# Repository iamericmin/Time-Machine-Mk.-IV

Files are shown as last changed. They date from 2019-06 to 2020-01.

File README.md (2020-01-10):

# Time Machine Mk. IV
# [Full write-up is on my website!](https://iamericmin.github.io/tm4.html)
Peekaboo!
## Homebrew cyberpunk Cortex M4 "smart"watch with BLE radio

Project status: all bugs not fixed before January 1st 2020 are now officially features

# Hi!
I am Eric Min and I'm a 18 year old teenager from Seoul, South Korea. This is my first major project in circuit design and firmware development. It is a cyberpunk inspired wristwatch leveraging the low-power and Bluetooth Low Energy features of Nordic's nRF52832. I think it looks pretty dope! :)

# THE JUICY STUFF:
-   PROCESSOR: nRF52832 Soc. 64MHz ARM cortex M4 with 64k RAM and 512k flash.
-   FIRMWARE: Espruino JS interpreter + JS code layer
-   POWER: 12mm CR1225 coin cell battery. About two weeks of battery life.
-   DISPLAY: If you can call it a display. Dual 7-segment LEDs with five auxiliary LEDs.
-   INPUT: Triple momentary tactile switches.
-   SOUND: Mini piezo speaker.
-   DIMENSIONS: 43.18mm width and length, 10.2mm thickness.
-   STRAP: 22mm NATO strap.

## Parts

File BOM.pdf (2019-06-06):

Description | Quantity Unit Price Extended Price
SWITCH TACTILE SPST-NO 0.05A 32V | 3 | 0.52 $0.52
AUDIO MAGNETIC XDCR 2-4V SMD | 1 | 3.03 $6.06
7-SEG. DISPLAY THROUGH HOLE | 2 | 1.59 $4.77
BATTERY RETAINER COIN 12MM SMD | 1 | 0.91 $3.64
RES SMD 330 OHM 0.5% 1/10W 0805 | 12 | 0.11 $0.55
MDBT42Q NRF52832 BASED BLE MODUL | 1 | 10.1 $60.60
LED BLUE CLEAR 1206 SMD | 5 | 0.39 $2.73

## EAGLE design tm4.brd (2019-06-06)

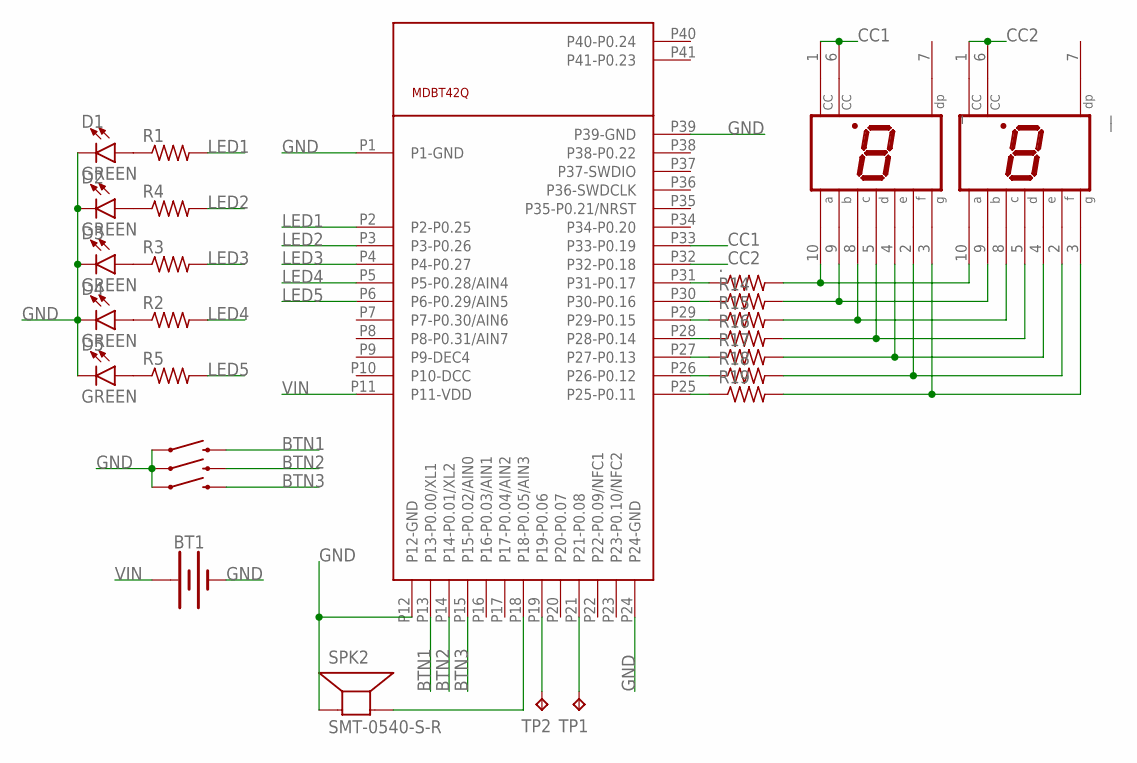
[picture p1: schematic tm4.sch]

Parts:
.: R-US_M0805; M0805
BT1: BATTERY-12MM_SMD; BATTCON_12MM
D1, D2, D3, D4, D5: GREEN; LED-1206
R1, R2, R3, R4, R5, R14, R15, R16, R17, R18, R19: R-US_M0805; M0805
SPK2: SMT-0540-S-R
TP1, TP2: TPTP19R; TP19R
U$1: MDBT42Q; MDBT40
_: HD-A103; HDSP-A
__: HD-A103; HDSP-A
____: MOMENTARY-SWITCH-SPST-SMD-6.2MM-TALL; TACTILE_SWITCH_SMD_6.2MM_TALL
_____: MOMENTARY-SWITCH-SPST-SMD-6.2MM-TALL; TACTILE_SWITCH_SMD_6.2MM_TALL
______: MOMENTARY-SWITCH-SPST-SMD-6.2MM-TALL; TACTILE_SWITCH_SMD_6.2MM_TALL

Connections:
A: ..2, _.10 (A), __.10 (A)
B: R14.2, _.9 (B), __.9 (B)
BTN1: U$1.P13 (P13-P0.00/XL1), ____.B2 (2)
BTN2: U$1.P14 (P14-P0.01/XL2), _____.B2 (2)
BTN3: U$1.P15 (P15-P0.02/AIN0), ______.B2 (2)
C: R15.2, _.8 (C), __.8 (C)
CC1: U$1.P33 (P33-P0.19), _.1 (CC), _.6 (CC)
CC2: U$1.P32 (P32-P0.18), __.1 (CC), __.6 (CC)
D: R16.2, _.5 (D), __.5 (D)
E: R17.2, _.4 (E), __.4 (E)
F: R18.2, _.2 (F), __.2 (F)
G: R19.2, _.3 (G), __.3 (G)
GND: BT1.GND (-), D1.C, D2.C, D3.C, D4.C, D5.C, SPK2.- (+), U$1.P1 (P1-GND), U$1.P12 (P12-GND), U$1.P24 (P24-GND), U$1.P39 (P39-GND), ____.A2 (1), _____.A2 (1), ______.A2 (1)
LED1: R1.2, U$1.P2 (P2-P0.25)
LED2: R4.2, U$1.P3 (P3-P0.26)
LED3: R3.2, U$1.P4 (P4-P0.27)
LED4: R2.2, U$1.P5 (P5-P0.28/AIN4)
LED5: R5.2, U$1.P6 (P6-P0.29/AIN5)
unnamed: ..1, U$1.P31 (P31-P0.17)
unnamed: R14.1, U$1.P30 (P30-P0.16)
unnamed: R15.1, U$1.P29 (P29-P0.15)
unnamed: D1.A, R1.1
unnamed: D2.A, R4.1
unnamed: D3.A, R3.1
unnamed: D4.A, R2.1
unnamed: R16.1, U$1.P28 (P28-P0.14)
unnamed: R17.1, U$1.P27 (P27-P0.13)
unnamed: R18.1, U$1.P26 (P26-P0.12)
unnamed: R19.1, U$1.P25 (P25-P0.11)
unnamed: SPK2.+ (-), U$1.P18 (P18-P0.05/AIN3)
unnamed: D5.A, R5.1
unnamed: TP1.TP, U$1.P21 (P21-P0.08)
unnamed: TP2.TP, U$1.P19 (P19-P0.06)
VIN: BT1.PWR@1 (+), U$1.P11 (P11-VDD)

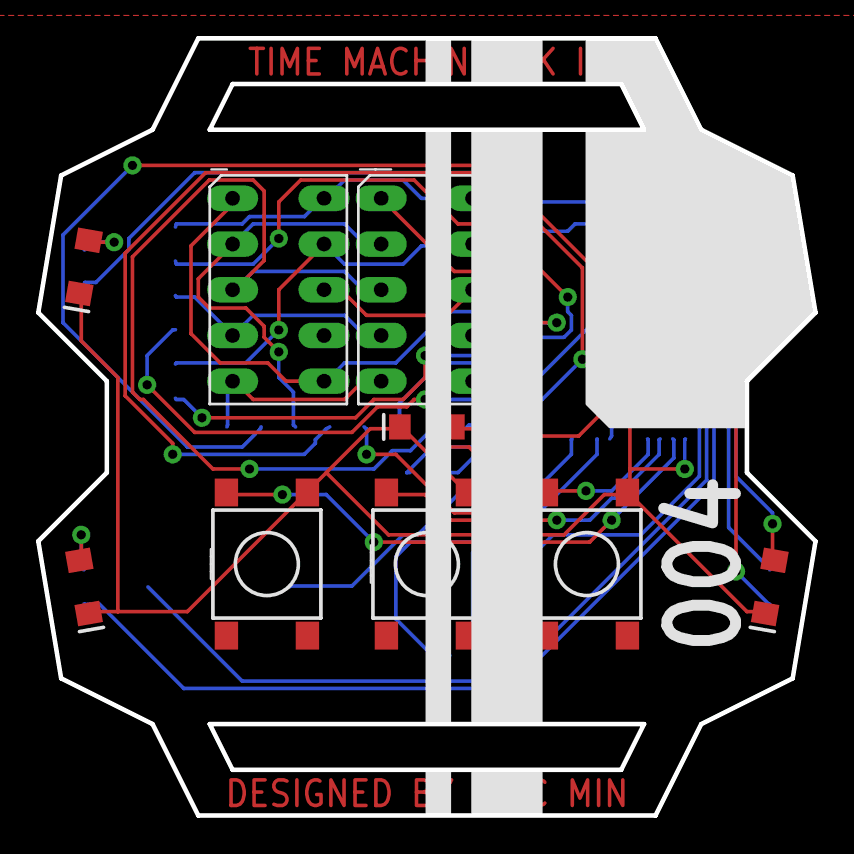
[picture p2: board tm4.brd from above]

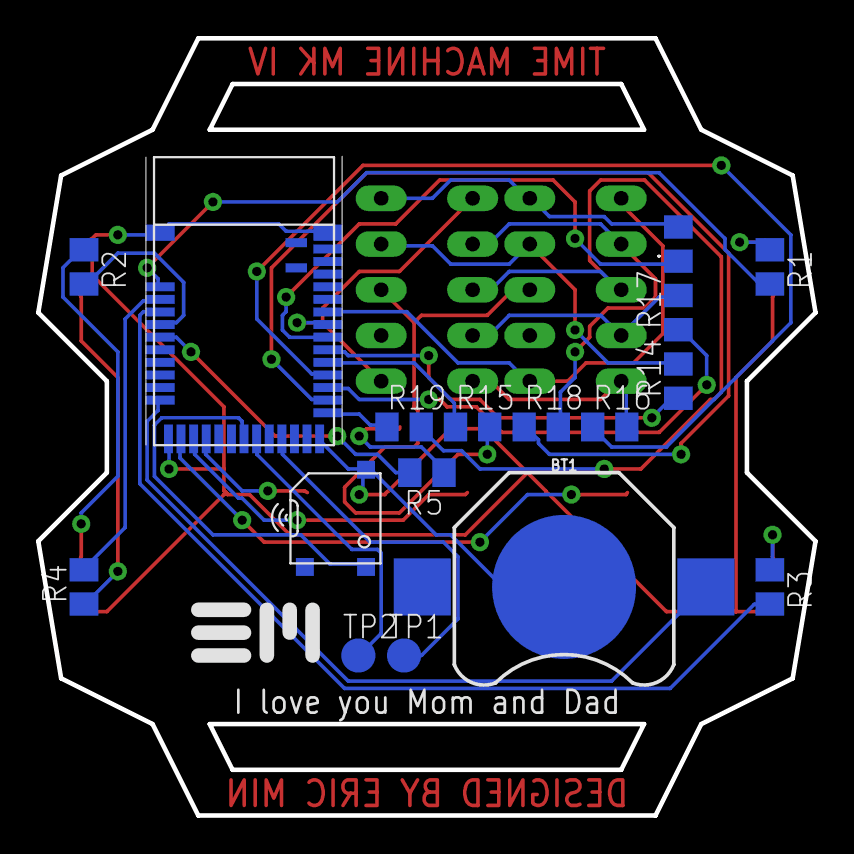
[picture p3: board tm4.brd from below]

Board: 2 copper layers, 43.2 x 43.2 mm, 27 parts (17 on the bottom side), 34 nets.

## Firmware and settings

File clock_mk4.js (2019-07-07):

/*

    
    ###  ###  ###   _______                   __  ___           __    _                ###  ###  ###
   ###  ###  ###   /_  __(_)___ ___  ___     /  |/  /___ ______/ /_  (_)___  ___      ###  ###  ###
  ###  ###  ###     / / / / __ `__ \/ _ \   / /|_/ / __ `/ ___/ __ \/ / __ \/ _ \    ###  ###  ###
 ###  ###  ###     / / / / / / / / /  __/  / /  / / /_/ / /__/ / / / / / / /  __/   ###  ###  ###
###  ###  ###     /_/ /_/_/ /_/ /_/\___/  /_/  /_/\__,_/\___/_/ /_/_/_/ /_/\___/   ###  ###  ###

Digital watch made by Eric Min
Based on Espruino firmware by Gordon Williams

*/

var dg1 = D19;
var dg2 = D18;
var A = D17;
var B = D16;
var C = D15;
var D = D14;
var E = D13;
var F = D12;
var G = D11;
var l1 = D25;
var l2 = D26;
var l3 = D27;
var l4 = D28;
var l5 = D29;
var left = D0;
var select = D1;
var right = D2;
var spk = D5;

/*
pinMode(dg1, "output");
pinMode(dg2, "output");
pinMode(A, "output");
pinMode(B, "output");
pinMode(C, "output");
pinMode(D, "output");
pinMode(E, "output");
pinMode(F, "output");
pinMode(G, "output");
pinMode(l1, "output");
pinMode(l2, "output");
pinMode(l3, "output");
pinMode(l4, "output");
pinMode(l5, "output");
pinMode(spk, "output");
*/

function allClear() {
  digitalWrite(A, 0);
  digitalWrite(B, 0);
  digitalWrite(C, 0);
  digitalWrite(D, 0);
  digitalWrite(E, 0);
  digitalWrite(F, 0);
  digitalWrite(G, 0);
  digitalWrite(dg1, 1);
  digitalWrite(dg2, 1);
  digitalWrite(l1, 0);
  digitalWrite(l2, 0);
  digitalWrite(l3, 0);
  digitalWrite(l4, 0);
  digitalWrite(l5, 0);
}

function clearDigits() {
  digitalWrite(A, 0);
  digitalWrite(B, 0);
  digitalWrite(C, 0);
  digitalWrite(D, 0);
  digitalWrite(E, 0);
  digitalWrite(F, 0);
  digitalWrite(G, 0);
}

function freq(f) { 
  if (f===0) digitalWrite(spk,0);
  else analogWrite(spk, 0.5, { freq: f } );
}

/*
A little help?

            ----A----
            |       |
            F       B
            |       |
            ----G----
            |       |
            E       C
            |       |
            ----D----
*/

function one() {
  digitalWrite(F, 1);
  digitalWrite(E, 1);
}

function two() {
  digitalWrite(A, 1);
  digitalWrite(B, 1);
  digitalWrite(G, 1);
  digitalWrite(E, 1);
  digitalWrite(D, 1);
}

function three() {
  digitalWrite(A, 1);
  digitalWrite(B, 1);
  digitalWrite(G, 1);
  digitalWrite(C, 1);
  digitalWrite(D, 1);
}

function four() {
  digitalWrite(F, 1);
  digitalWrite(G, 1);
  digitalWrite(B, 1);
  digitalWrite(C, 1);
}

function five() {
  digitalWrite(A, 1);
  digitalWrite(F, 1);
  digitalWrite(G, 1);
  digitalWrite(C, 1);
  digitalWrite(D, 1);
}

function six() {
  digitalWrite(A, 1);
  digitalWrite(F, 1);
  digitalWrite(E, 1);
  digitalWrite(G, 1);
  digitalWrite(C, 1);
  digitalWrite(D, 1);
}

function seven() {
  digitalWrite(F, 1);
  digitalWrite(A, 1);
  digitalWrite(B, 1);
  digitalWrite(C, 1);
}

function eight() {
  digitalWrite(A, 1);
  digitalWrite(B, 1);
  digitalWrite(C, 1);
  digitalWrite(D, 1);
  digitalWrite(E, 1);
  digitalWrite(F, 1);
  digitalWrite(G, 1);
}

function nine() {
  digitalWrite(A, 1);
  digitalWrite(B, 1);
  digitalWrite(C, 1);
  digitalWrite(G, 1);
  digitalWrite(F, 1);
  digitalWrite(D, 1);
}

function zero() {
  digitalWrite(A, 1);
  digitalWrite(B, 1);
  digitalWrite(C, 1);
  digitalWrite(D, 1);
  digitalWrite(E, 1);
  digitalWrite(F, 1);
}

function aa() {
  digitalWrite(A, 1);
  digitalWrite(B, 1);
  digitalWrite(C, 1);
  digitalWrite(E, 1);
  digitalWrite(F, 1);
  digitalWrite(G, 1);
}

function bb() {
  digitalWrite(C, 1);
  digitalWrite(D, 1);
  digitalWrite(E, 1);
  digitalWrite(F, 1);
  digitalWrite(G, 1);
}

function cc() {
  digitalWrite(A, 1);
  digitalWrite(F, 1);
  digitalWrite(E, 1);
  digitalWrite(D, 1);

}

function dd() {
  digitalWrite(B, 1);
  digitalWrite(C, 1);
  digitalWrite(G, 1);
  digitalWrite(E, 1);
  digitalWrite(D, 1);
}

function ee() {
  digitalWrite(A, 1);
  digitalWrite(F, 1);
  digitalWrite(G, 1);
  digitalWrite(E, 1);
  digitalWrite(D, 1);
}

function ff() {
  digitalWrite(A, 1);
  digitalWrite(F, 1);
  digitalWrite(G, 1);
  digitalWrite(E, 1);
}

function gg() {
  digitalWrite(A, 1);
  digitalWrite(F, 1);
  digitalWrite(E, 1);
  digitalWrite(D, 1);
  digitalWrite(C, 1);
}

function hh() {
  digitalWrite(F, 1);
  digitalWrite(E, 1);
  digitalWrite(G, 1);
  digitalWrite(C, 1);
  digitalWrite(B, 1);
}

function ii() {
  digitalWrite(B, 1);
  digitalWrite(C, 1);
}

function jj() {
  digitalWrite(B, 1);
  digitalWrite(C, 1);
  digitalWrite(E, 1);
  digitalWrite(D, 1);
}

function pp() {
  digitalWrite(A, 1);
  digitalWrite(F, 1);
  digitalWrite(E, 1);
  digitalWrite(G, 1);
  digitalWrite(B, 1);
}

function rr() {
  digitalWrite(G, 1);
  digitalWrite(E, 1);
}

function ss() {
  five();
}

function tt() {
  digitalWrite(D, 1);
  digitalWrite(F, 1);
  digitalWrite(E, 1);
  digitalWrite(G, 1);
}

function ll() {
  digitalWrite(D, 1);
  digitalWrite(F, 1);
  digitalWrite(E, 1);
}

function nn() {
  digitalWrite(D, 1);
  digitalWrite(F, 1);
  digitalWrite(G, 1);
}

function uu() {
  digitalWrite(D, 1);
  digitalWrite(F, 1);
  digitalWrite(E, 1);
}

function space() {
  digitalWrite(A, 0);
  digitalWrite(B, 0);
  digitalWrite(C, 0);
  digitalWrite(D, 0);
  digitalWrite(E, 0);
  digitalWrite(F, 0);
  digitalWrite(G, 0);
}

/*
function menu() {
  itemNum = 3;
  while(digitalRead(select) !== 0) {
    if (digitalRead(right, 1) === 0) {
      itemNum += 1;
    }
    if (itemNum == 4){ itemNum = 1;}
    else if (itemNum == 1) {
      showDisp("p", "r", BTN, 0);
    }
    else if (itemNum == 2) {
      showDisp("s", "t", BTN, 0);
    }
    else if (itemNum == 3) {
      showDisp("a", "l", BTN, 0);
    }
  }
}
*/

function data() {
  time = new Date();
  month = time.getMonth();
  date = time.getDate();
  hour = time.getHours();
  if (hour > 12) {
    hour = hour - 12;
  }
  if (hour === 0) {
    hour = 12;
  }
  hourFirstDigit = hour.toString()[0];
  hourSecondDigit = hour.toString()[1];
  min = time.getMinutes();
  minFirstDigit = min.toString()[0];
  minSecondDigit = min.toString()[1];
}
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

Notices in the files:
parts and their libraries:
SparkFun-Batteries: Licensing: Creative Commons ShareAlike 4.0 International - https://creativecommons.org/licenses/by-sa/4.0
